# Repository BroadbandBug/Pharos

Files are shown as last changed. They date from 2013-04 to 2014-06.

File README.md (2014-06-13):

Pharos
======

APRS MSP430 Beacon
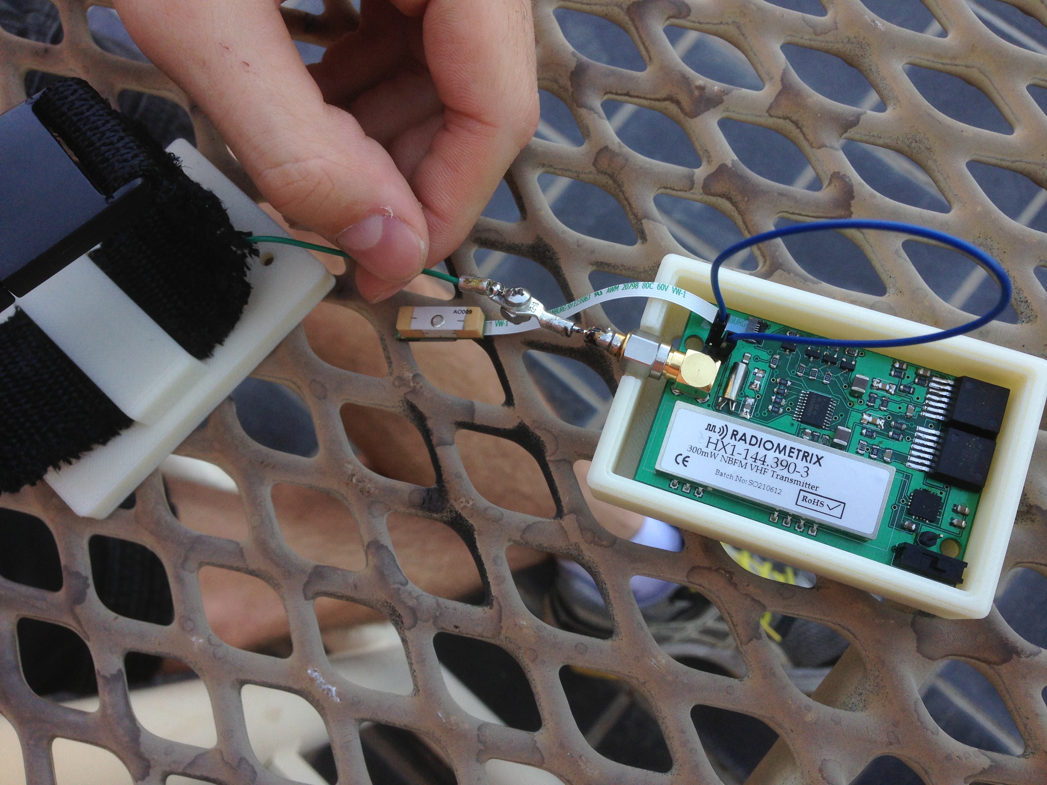
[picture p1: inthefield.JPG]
Beacon working in the field

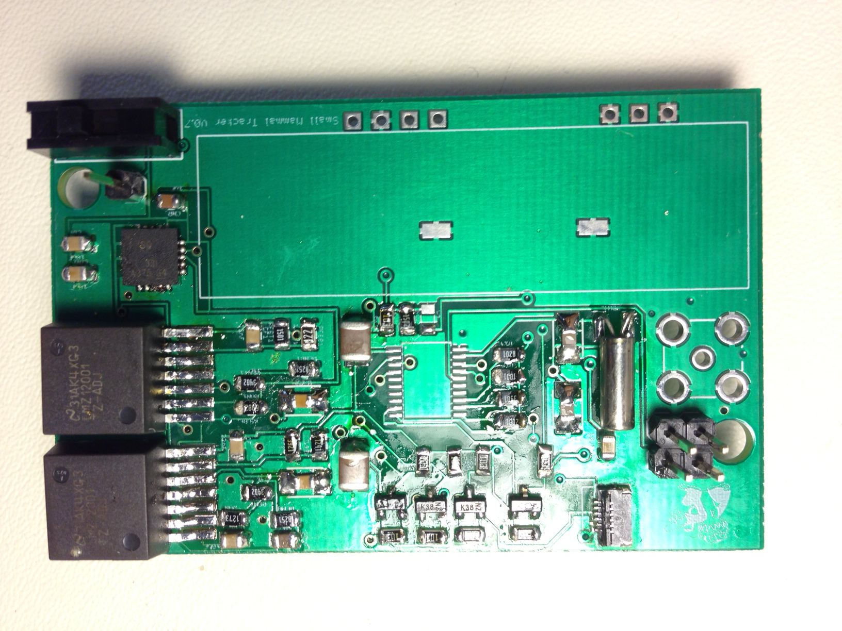
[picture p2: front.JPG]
Front of Board

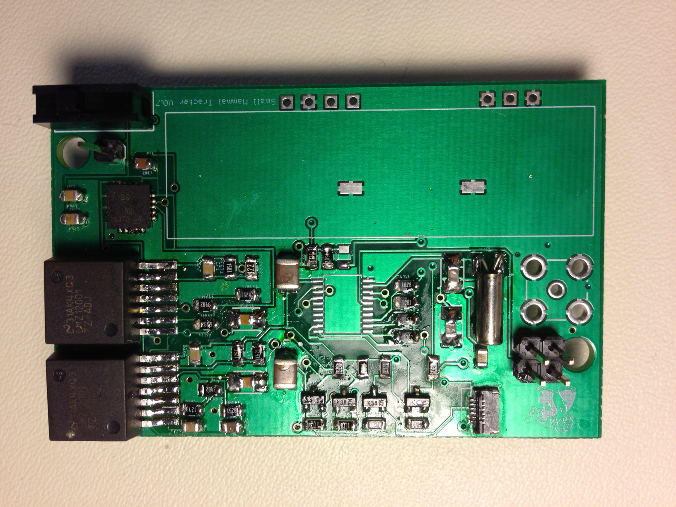
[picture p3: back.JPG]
Back of Board


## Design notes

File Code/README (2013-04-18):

Project Pharos

Description:
  A small APRS beacon for the tracking of the golden lion tamarin monkey was prototyped. The beacon was required to be low power and use GPS as a source of position acquisition.

Main Components:
  MSP430G2553
  RadioMetrix HX1 @ 144.390 MHz
  GP-2103 SiRF IV GPS
  CR2450 Battery

Schematic, Eagle files, and parts list can be found in Hardware Folder.

How to use:
  1) Construct the board as described.
  2) Install Code Composer Studio  V5.3.0 or greater
  3) Connect TEST RST GND pins from MSP430 Launchpad to TEST RST GND pins on final board.
  4) ???
  5) Profit

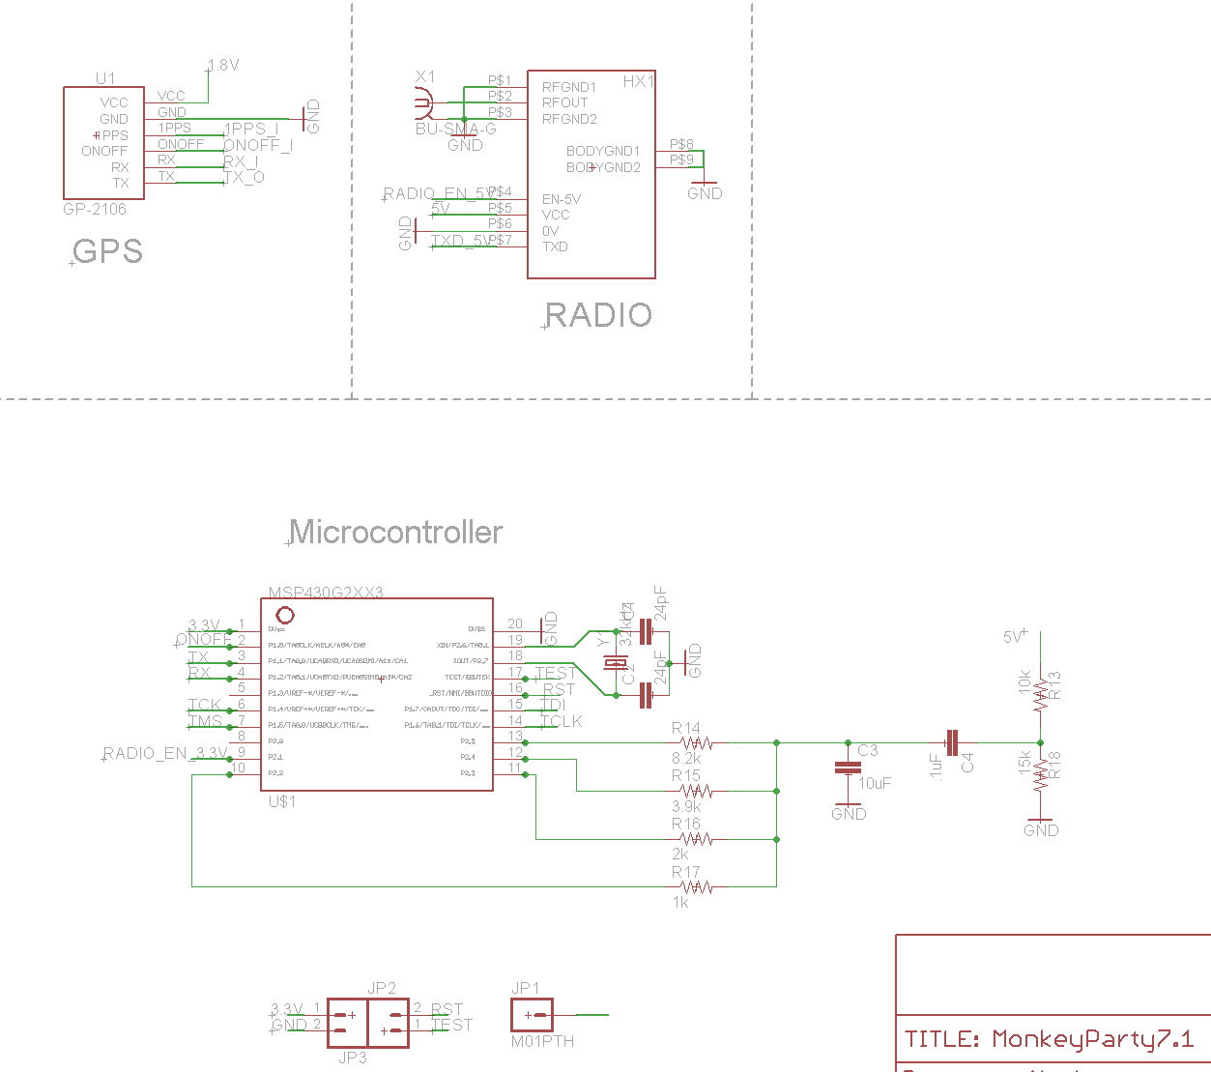
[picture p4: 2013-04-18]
Schematics/Schematic2.PNG

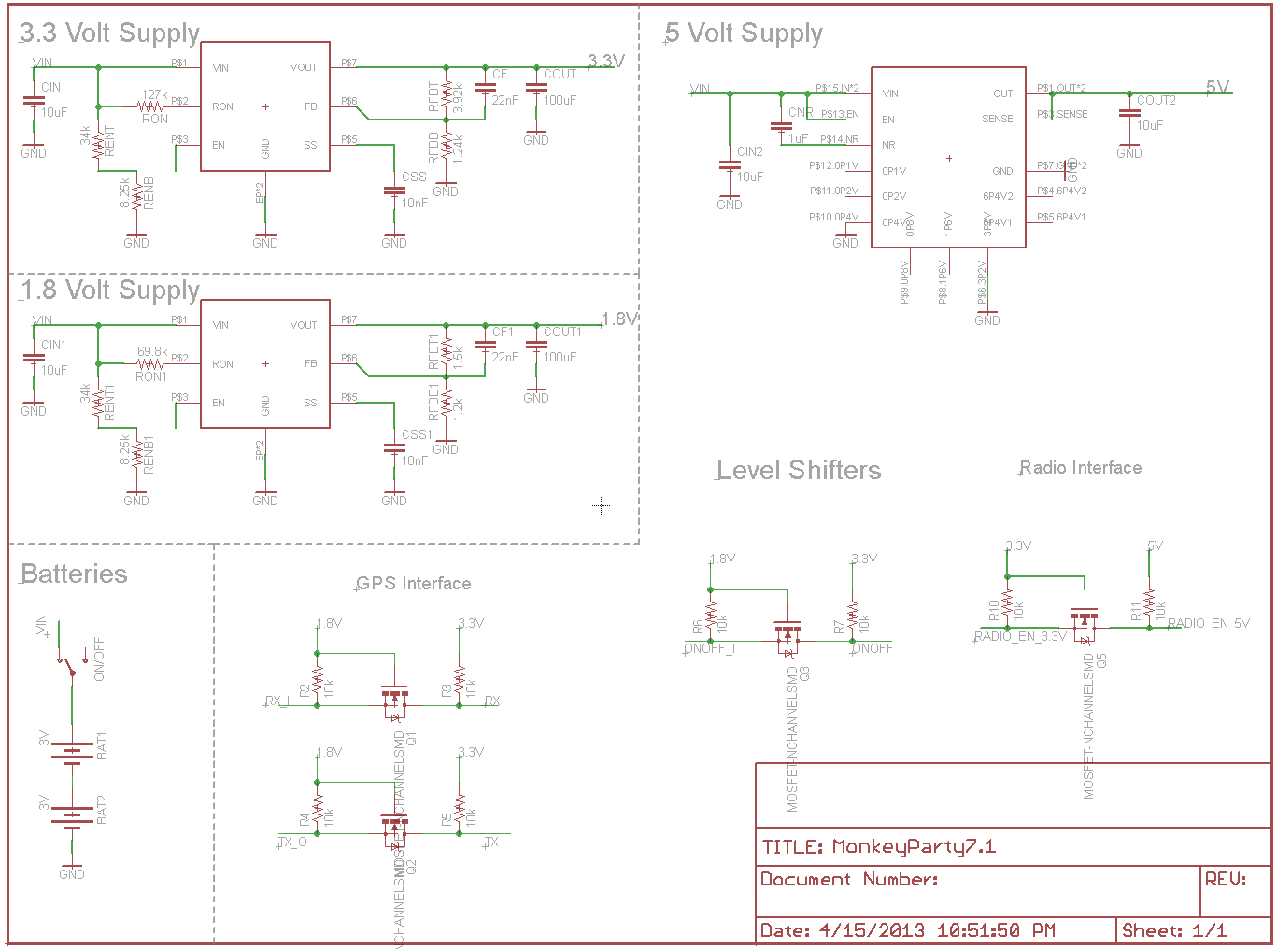
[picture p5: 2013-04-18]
Schematics/Schematic1.PNG

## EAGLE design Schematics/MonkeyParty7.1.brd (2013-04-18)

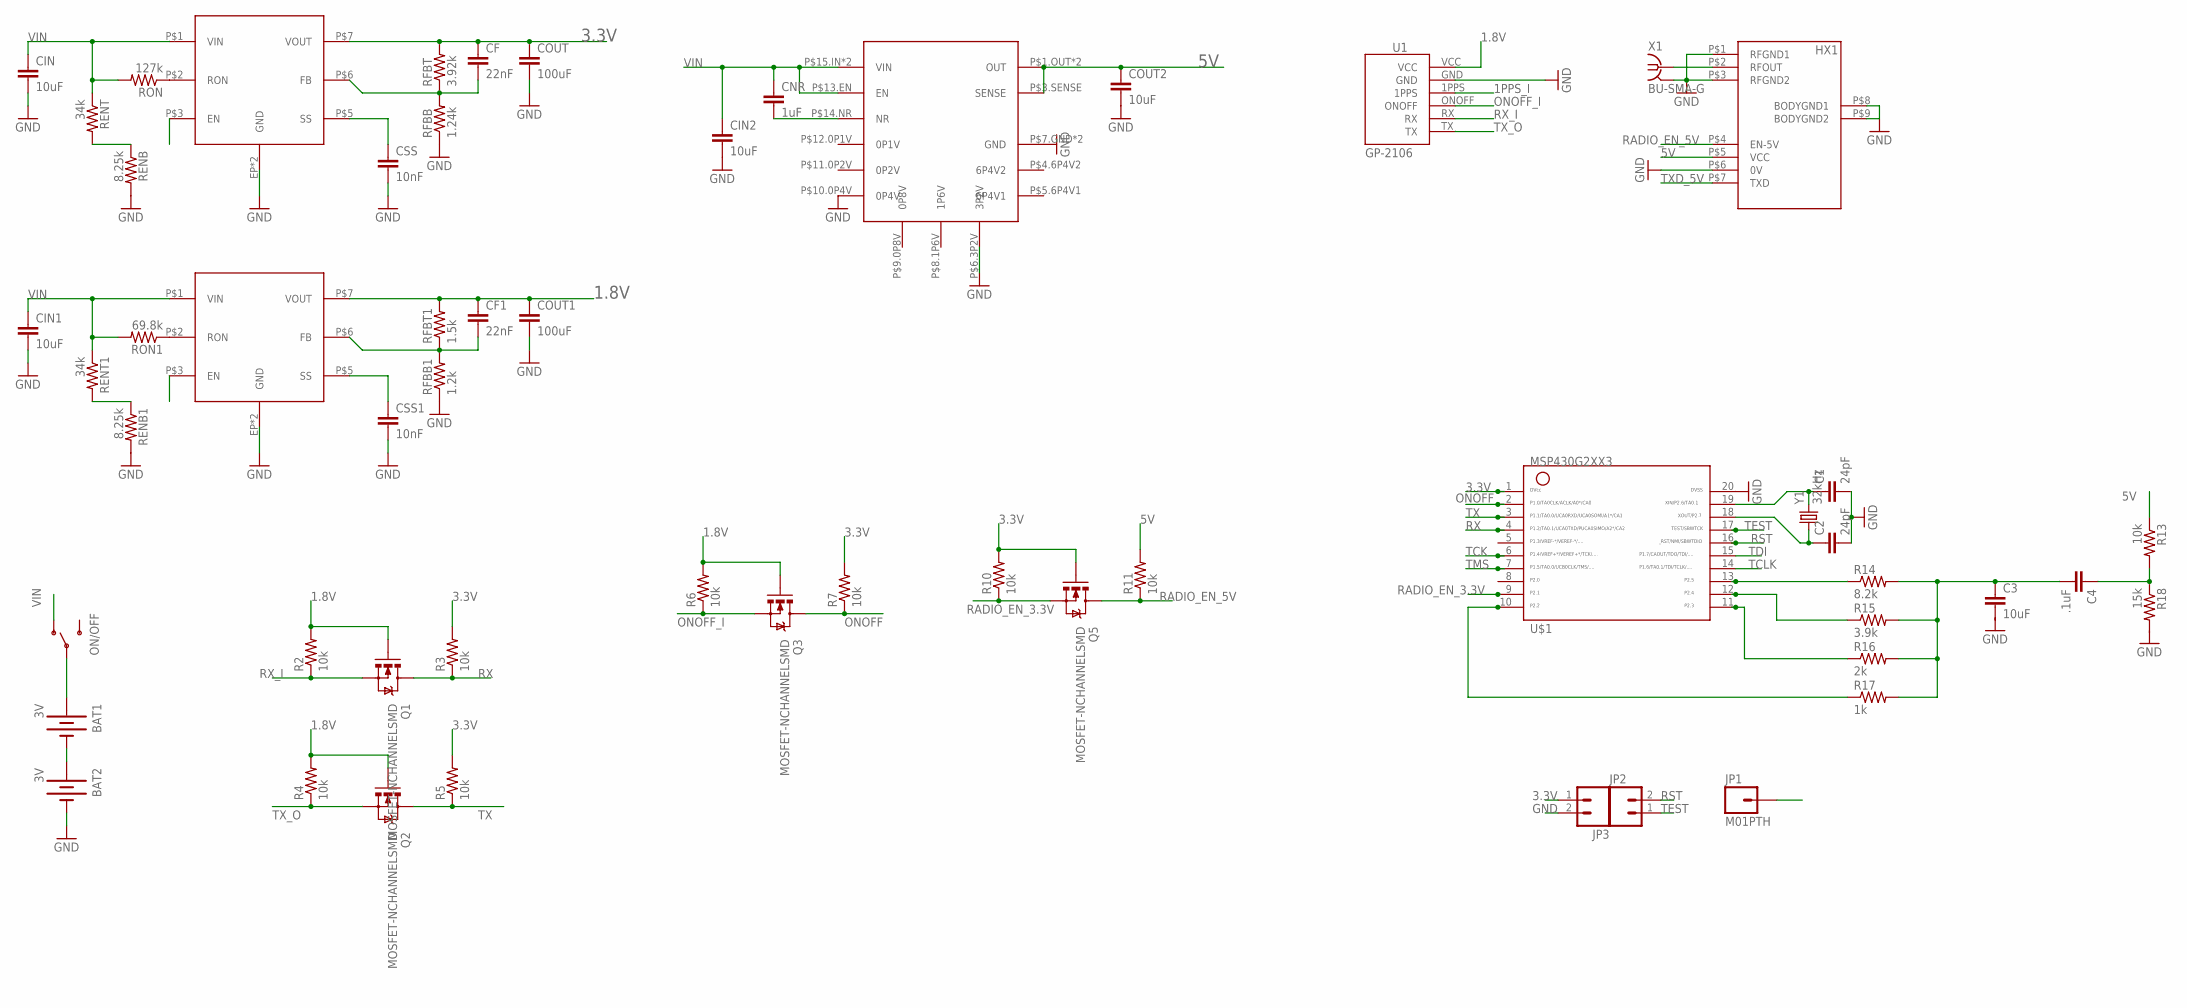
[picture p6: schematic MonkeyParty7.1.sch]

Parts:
1.8VREG, 3.3VREG: LMZ12001; TO-PMOD7PIN
5VREG: TPS7A4700; S-PVQFN-N20
BAT1, BAT2: 3V; BATTCON_245MM
C1, C2: 24pF; 1210
C3: 10uF; 0805
C4: .1uF; 0805
CF, CF1: 22nF; 0805
CIN, CIN1, CIN2: 10uF; 0805
CNR: 1uF; 0805
COUT, COUT1: 100uF; 1210
COUT2: 10uF; 0805
CSS, CSS1: 10nF; 1210
JP1: M01PTH; 1X01
JP2, JP3: M02PTH; 1X02
ON/OFF: SWITCH-SPSTKIT; SWITCH-SPDT_KIT
Q1, Q2, Q3, Q5: MOSFET-NCHANNELSMD; SOT23-3
R2, R3, R4, R5, R6, R7, R10, R11, R13: 10k; 0805
R14: 8.2k; 0805
R15: 3.9k; 0805
R16: 2k; 0805
R17: 1k; 0805
R18: 15k; 0805
RENB, RENB1: 8.25k; 0805
RENT, RENT1: 34k; 0805
RFBB: 1.24k; 0805
RFBB1: 1.2k; 0805
RFBT: 3.92k; 0805
RFBT1: 1.5k; 0805
RON: 127k; 0805
RON1: 69.8k; 0805
U1: GP-2106
U$1: G2XX3---PW20; PW20
U$2: HX1
X1: BU-SMA-G
Y1: 32kHz; CRYSTAL-32KHZ-SMD

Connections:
1.8V: 1.8VREG.P$7 (VOUT), CF1.1, COUT1.1, Q1.1 (G), Q2.1 (G), Q3.1 (G), R2.2, R4.2, R6.2, RFBT1.2, U1.VCC
1PPS_I: U1.1PPS
3.3V: 3.3VREG.P$7 (VOUT), CF.1, COUT.1, JP3.1, Q5.1 (G), R3.2, R5.2, R7.2, R10.2, RFBT.2, U$1.1
5V: 5VREG.P$1.OUT (OUT), 5VREG.P$3.SENSE (SENSE), 5VREG.P$20.OUT (OUT), COUT2.1, R11.2, R13.1, U$2.P$5 (VCC)
GND: 1.8VREG.EP (GND), 1.8VREG.P$4 (GND), 3.3VREG.EP (GND), 3.3VREG.P$4 (GND), 5VREG.P$6.3P2V (3P2V), 5VREG.P$7.GND (GND), 5VREG.P$10.0P4V (0P4V), 5VREG.P$21.GND (GND), BAT2.2 (-), C1.2, C2.2, CIN.2, CIN1.2, CIN2.2, COUT.2, COUT1.2, COUT2.2, CSS.2, CSS1.2, JP3.2, RENB.2, RENB1.2, RFBB.1, RFBB1.1, U1.GND, U$1.20, U$2.P$1 (RFGND1), U$2.P$3 (RFGND2), U$2.P$6 (0V), U$2.P$8 (BODYGND1), U$2.P$9 (BODYGND2), X1.2, X1.3 (2), X1.4 (2), X1.5 (2)
unnamed: 3.3VREG.P$2 (RON), RON.1
unnamed: U$2.P$2 (RFOUT), X1.1
unnamed: RENB.1, RENT.2
unnamed: BAT1.2 (-), BAT2.1 (+)
unnamed: 3.3VREG.P$5 (SS), CSS.1
unnamed: 3.3VREG.P$6 (FB), CF.2, RFBB.2, RFBT.1
unnamed: 1.8VREG.P$2 (RON), RON1.1
unnamed: BAT1.1 (+), ON/OFF.2
unnamed: RENB1.1, RENT1.2
unnamed: 1.8VREG.P$5 (SS), CSS1.1
unnamed: 1.8VREG.P$6 (FB), CF1.2, RFBB1.2, RFBT1.1
unnamed: 5VREG.P$14.NR (NR), CNR.2
unnamed: C1.1, U$1.19, Y1.X2 (2)
unnamed: C2.1, U$1.18, Y1.X1 (1)
unnamed: R14.1, U$1.13
unnamed: R15.1, U$1.12
unnamed: R16.1, U$1.11
unnamed: R17.1, U$1.10
ONOFF: Q3.3 (D), R7.1, U$1.2
ONOFF_I: Q3.2 (S), R6.1, U1.ONOFF
RADIO_EN_3.3V: Q5.2 (S), R10.1, U$1.9
RADIO_EN_5V: Q5.3 (D), R11.1, U$2.P$4 (EN-5V)
RST: JP2.2, U$1.16
RX: Q1.3 (D), R3.1, U$1.4
RX_I: Q1.2 (S), R2.1, U1.RX
TCK: U$1.6
TCLK: U$1.14
TDI: U$1.15
TEST: JP2.1, U$1.17
TMS: U$1.7
TX: Q2.3 (D), R5.1, U$1.3
TXD_3.3V: C3.1, C4.2, R14.2, R15.2, R16.2, R17.2
TXD_5V: C4.1, R13.2, R18.1, U$2.P$7 (TXD)
TX_O: Q2.2 (S), R4.1, U1.TX
VIN: 1.8VREG.P$1 (VIN), 1.8VREG.P$3 (EN), 3.3VREG.P$1 (VIN), 3.3VREG.P$3 (EN), 5VREG.P$13.EN (EN), 5VREG.P$15.IN (VIN), 5VREG.P$16.IN (VIN), CIN.1, CIN1.1, CIN2.1, CNR.1, JP1.1, ON/OFF.1 (O), RENT.1, RENT1.1, RON.2, RON1.2

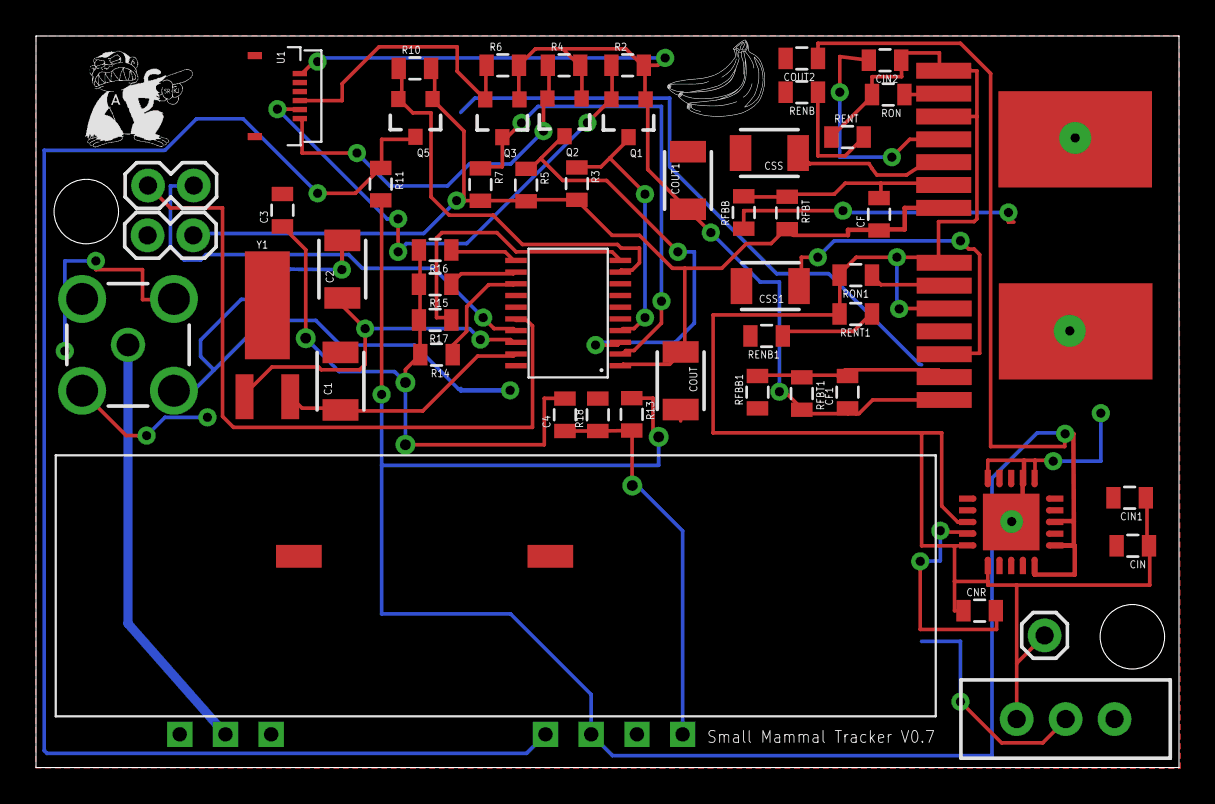
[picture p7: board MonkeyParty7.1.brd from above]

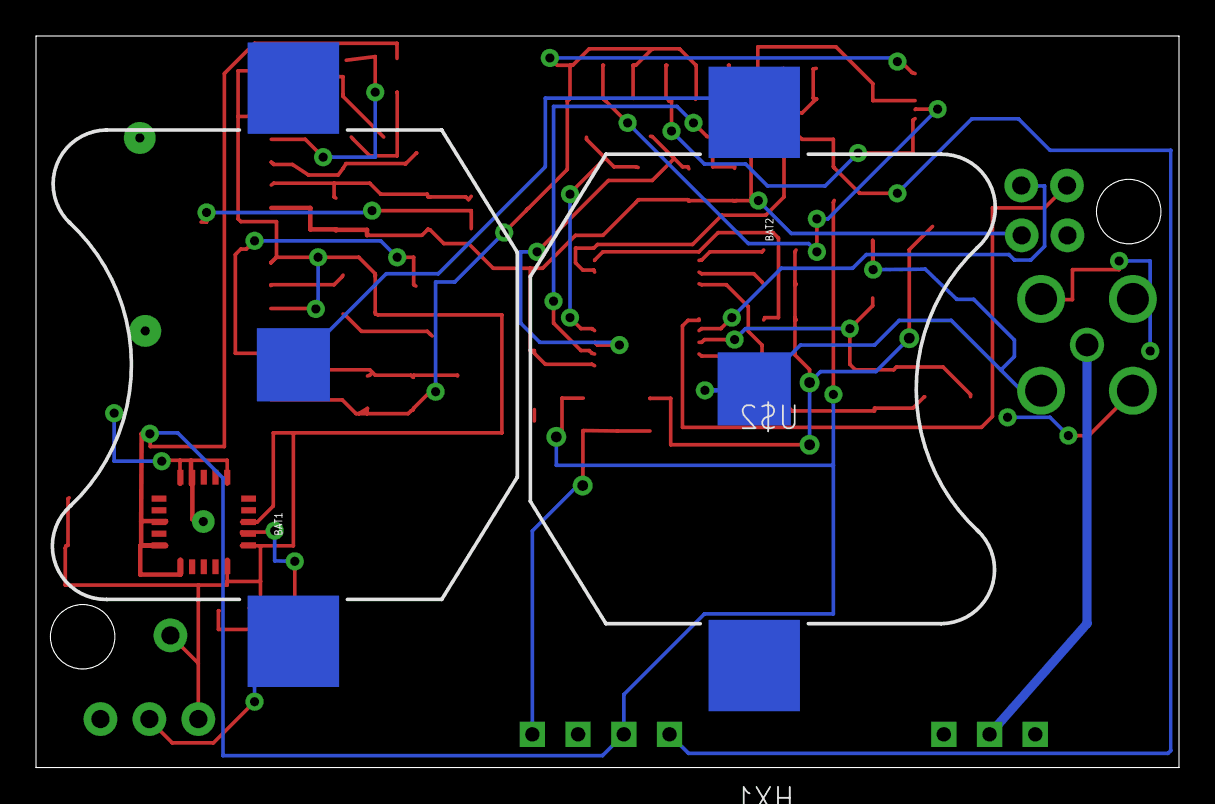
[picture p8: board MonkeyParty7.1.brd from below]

Board: 2 copper layers, 63.5 x 40.6 mm, 57 parts (2 on the bottom side), 35 nets.

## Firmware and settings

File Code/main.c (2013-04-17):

#include <msp430G2553.h>
#include <string.h>
#include <stdint.h>
#include "global.h"
#include "gps.h"
#include "sleep.h"
#include "ax25.h"

bool sleep;

uint8_t main ( void ){
  char *gpgga;
  aprs_header header;
  header.CALL_D = "APRS  ";
  header.CALL_D_SSID = 0xE0;
  header.CALL_S = "KF7IYK";
  header.CALL_S_SSID = 0x47;
  header.Control = 0xC0;
  header.PID = 0x0F;

  //P2REN |= BIT1;
  P2DIR |= BIT1;
  P2OUT &= ~BIT1;
  while(1){
    //GPGGA will contain the entire GPGGA string
    //that is received from the gps.
    //GPS_wakeup();
    do{
      GPS_setup();
      gpgga = GPS_aquire();
      ax_timer_setup();

    }while(!send_packet( header, gpgga ));
    P2OUT = 0x00;
    Sleep();

  }
}

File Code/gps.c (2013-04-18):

#include "global.h"
#include <msp430.h>
#include <string.h>
#include <stdlib.h>
#include "gps.h"

volatile bool gpgga_detect = false;
volatile bool gps_on = false;
char temp_uart[200];
uint8_t string_index;
uint8_t k;
uint8_t wait;

void delay(unsigned int ms)
{
while (ms>0){
  ms--;
  __delay_cycles(4000);
  }
}

void GPS_setup( void ){
  //Kick the Dog
  WDTCTL = WDTPW + WDTHOLD; // Stop WDT
  if (CALBC1_8MHZ==0xFF){   // If calibration constant erased
    while(1);            // do not load, trap CPU!!
  }

  //Configuration of Clock cycles
  DCOCTL = 0;               // Select lowest DCOx and MODx settings
  BCSCTL1 = CALBC1_8MHZ;    // Set DCO
  DCOCTL = CALDCO_8MHZ;
  UCA0CTL1 |= UCSSEL_2;     // SMCLK
  P1SEL = BIT1 + BIT2;      // P1.1 = RXD, P1.2=TXD
  P1SEL2 = BIT1 + BIT2;     // P1.1 = RXD, P1.2=TXD
  P1DIR = BIT0 + BIT6;      // P1.0 & P1.6 Output
  //P1OUT = BIT0;             // LED1 on

  //Configuration of UART
  UCA0BR0 = 0x82;  // 8MHz 4800 UCA0BR0 = Frequency/baud rate
  UCA0BR1 = 0x06;   // 8MHz 4800
  UCA0MCTL = 0x0c;     // Modulation UCBRSx = 6
  UCA0CTL1 &= ~UCSWRST;   // **Initialize USCI state machine**
  IE2 |= UCA0RXIE;  // Enable USCI_A0 RX interrupt
  __bis_SR_register(GIE); // Enter LPM0, interrupts enabled
}

char* GPS_aquire( void ){
  char* gpgga;
  volatile bool sentence_validity = false;
  volatile uint8_t gpgga_caps = 0;
  //Wake up GPS by toggling on off pin
  gps_on = false;
  do{
    GPS_toggle();
  }while(!gps_on);
  gps_on = false;
  uint64_t test;
  //Delay with interrupts
  for(test = 0; test<4294967; test++);
  while(!gps_on){
	  GPS_toggle();
    //Ensure that the GPS is on
	  for(test = 0; test<4294967; test++);
  }

  do{
    IE2 |= UCA0RXIE;
    if (gpgga_detect){
      IE2 &= ~UCA0RXIE;
      gpgga_caps++;
      gpgga_detect = false;
      //strcpy(gpgga, temp_uart);
      gpgga = (char*)calloc(strlen(temp_uart),sizeof(char));
      strcpy(gpgga, temp_uart);
      sentence_validity = GPS_fix(gpgga);
      if(!sentence_validity) free(gpgga);
    }
    //if (!gps_on) GPS_toggle();
  }while(!sentence_validity);
  //Valid String has been parsed

  //Turn GPS OFF
  GPS_toggle();
  gps_on = false;
  return gpgga;
}

bool GPS_fix( char * gpgga_string){
  char * pcomma;
  bool valid;
  uint8_t num_commas = 0;
  pcomma = strchr(gpgga_string,',');
  while(pcomma != NULL){
    pcomma = strchr(pcomma+1,',');
    num_commas++;
    if( num_commas == 5 ){
      valid = (*(pcomma+1) == '1' || *(pcomma+1) == '2');
      *(pcomma+1)= '0';
      return valid;
    }
  }
  return false;
}

// USCI A0/B0 Receive ISR
#pragma vector=USCIAB0RX_VECTOR
__interrupt void USCI0RX_ISR(void){
  gps_on = true;

  if( memcmp(temp_uart, "$GPGGA",6)==0 && UCA0RXBUF == '$' ){
    gpgga_detect = true;
    string_index = 0;
    IE2 &= ~UCA0RXIE;
  }else if(UCA0RXBUF == '$'){
	string_index = 0;
  }
  temp_uart[string_index++] = UCA0RXBUF;
}

void GPS_toggle( void ){
  P1OUT |= BIT0;
  delay(200);
  P1OUT &= ~BIT0;
  delay(1500);
}

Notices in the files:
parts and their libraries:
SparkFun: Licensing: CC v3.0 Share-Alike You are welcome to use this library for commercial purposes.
